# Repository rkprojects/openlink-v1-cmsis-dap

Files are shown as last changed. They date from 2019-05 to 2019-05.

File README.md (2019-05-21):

# OpenLink-V1 CMSIS-DAP Debug Unit

Project home page: [https://ravikiranb.com/projects/cmsis-dap-debug/](https://ravikiranb.com/projects/cmsis-dap-debug/)

Build your own simple low cost CMSIS-DAP Debug Unit with USB HID interface 
to debug any ARM Cortex based microcontroller.

## Get Hardware and Firmware Files

$ git clone https://github.com/rkprojects/openlink-v1-cmsis-dap.git

# Hardware

* 55x30 mm board size.
* Low cost, Low pin count MCU STM32F070F6P6.
* Micro USB type B connector.
* 10-pin cortex debug connector
* All GPIOs on Headers.

## Design Files and Gerber

Schematic and PCB Layout files are in folder *openlink-v1-cmsis-dap/hardware/*  
Gerber files are in folder *openlink-v1-cmsis-dap/hardware/gerber/*  
BOM file is in folder *openlink-v1-cmsis-dap/hardware/docs/*  

Schematic and PCB Layout designed with [DipTrace Version 3.3.1.3 (Freeware)](https://diptrace.com/)  

## Notes on DRC

Before sending gerber files to fabrication please cross check the design rules 
with your PCB manufacturer's specifications and rerun DRC.

Current DRC violations waved off:  

* J3.1 and J3.5 Drill to SMD pad clearance is set to 12 mil as per my PCB manufacturer's specifications however 
in manufacturer's review it was waved off.  
* Y1.1 and Y1.2: Footprint design of Y1 (crystal) is a hybrid one (through hole pad overlapping SMD pad) 
with possibility of mounting either SMD or through hole crystal. Preferred part is SMD, however 
if you wish to use through hole part then while soldering raise the height of crystal such that 
metal case does not touch SMD pads.

# Firmware

## Software Requirements

* GCC ARM Toolchain
* [Keil MDK for ARM](http://www.keil.com/products/arm/mdk.asp) if you wish to validate the debug unit. 
Lite edition is sufficient for this project. 
You could also use [MDK for STM32F0](https://www2.keil.com/stmicroelectronics-stm32/mdk)
* [STM32CubeProgrammer](https://www.st.com/en/development-tools/stm32cubeprog.html) to flash firmware in USB DFU mode.
* Tested on OS: Windows 10 Build 14393.

## Source Code

Firmware source codes are in folder *openlink-v1-cmsis-dap/firmware/*

Pre-built binaries are present in the *openlink-v1-cmsis-dap/firmware/build/* directory. 
If you wish to rebuild then you may have to modify the Makefile to correctly point 
to toolchain binaries and run make.

## Flash Firmware

* Close J5.1-2 pins with jumper cap to boot from System memory in USB DFU mode.
* Connect the debug unit with USB cable to PC host.
* Start STM32CubeProgrammer and select USB as bootloader interface option. 
	* Click **Refresh** icon - Device information fields will get updated.
	* Click **Connect**.
	* Click on **Open file** tab and select *openlink_v1_cmsis_dap.hex* file 
	in *openlink-v1-cmsis-dap/firmware/build/* directory.
	* Click **Download** to flash.
	* Post download click **Disconnect**.
* Open J5.1-2 pins and close J5.2-3 pins with jumper cap to boot from Flash memory.
* Reset the board with **Reset** switch. There is no need to power cycle the board.
* Board should now get detected as USB HID device, cross check this in Device manager.

## Validate Debug Unit

* CMSIS DAP Firmware Validation project is in 
folder *openlink-v1-cmsis-dap/firmware/Validation/MDK5*.
* Follow the instructions in the readme.txt file there.
* In the step where CMSIS-DAP debugger needs to be selected, select **OpenLink-V1 CMSIS-DAP**.
* For specific example with LPC4357 MCU based target 
board refer to [project home page](https://ravikiranb.com/projects/cmsis-dap-debug/).

# Pending Stuff

* JTAG interface of the debug unit is not yet tested as 
all the Cortex-M boards I have are designed with SWD debug port. 
However JTAG interface is completely implemented in firmware.
* Current 10-pin debug connector (J4) is of through hole type with 1.27mm pitch. Commonly
used connectors are of SMD type compatible with samtec FTSH-105- styles.

# License

Copyright 2019 Ravikiran Bukkasagara <contact@ravikiranb.com>

This project uses multiple licenses:

*   
**Schematic and PCB Layout** design files are licensed under a 
[Creative Commons Attribution-ShareAlike 4.0 International License](http://creativecommons.org/licenses/by-sa/4.0/)
* **CMSIS DAP firmware code** is licensed under [Apache License, Version 2.0](http://www.apache.org/licenses/LICENSE-2.0)
* **STMicroelectronics supplied USB Middleware, HAL, LL drivers and startup source codes** are licensed 
under [Ultimate Liberty license SLA0044](http://www.st.com/SLA0044)
* **Code to bridge USB and DAP data flow** is licensed under [Apache License, Version 2.0](http://www.apache.org/licenses/LICENSE-2.0)
* Each source/header file specifies corresponding license/copyright notices.

All firmware source codes and hardware design files in this project are distributed on an "AS IS" BASIS,
WITHOUT WARRANTIES OR CONDITIONS OF ANY KIND, either express or implied.
See the License for the specific language governing permissions and
limitations under the License.

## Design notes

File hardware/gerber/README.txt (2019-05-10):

Filename meaning:

1) cmsis_dap.drl: NC Drill file, contains both plated and non-plated holes.
2) cmsis_dap.gbl: Gerber bottom copper layer.
3) cmsis_dap.gbo: Gerber bottom silk screen layer.
4) cmsis_dap.gbs: Gerber bottom solder mask layer.
5) cmsis_dap.gko: Gerber Board outline.
6) cmsis_dap.gtl: Gerber top copper layer.
7) cmsis_dap.gto: Gerber top silk screen layer.
8) cmsis_dap.gts: Gerber top solder mask layer.

Board Specifications:
Board Size: X = 55mm, Y = 30mm.

Board delivery form: Cut to single unit (No panel).

Layers: 2 (double sided)

Board Thickness: 1.6mm

Start copper thickness: 17.50 micron

Finished outer copper thickness: 35 micron

Surfach Finish: HAL

Solder mask color: Preferred Green. 
But for prototyping, manufacturer's choice if on shared project.

Silk screen text color: Preferred White. 
But for prototyping, manufacturer's choice if on shared project.

Impedance control: Not required.

Blind & Buried Via: Not present.

-END-

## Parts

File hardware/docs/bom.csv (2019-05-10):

# | RefDes | Value | Name | Pattern | Quantity | Description | Part Weblink | Alternate Part
1 | C1, C2, C3 | 0.1u | CAP_0805 | CAP_0805 | 3 | >= 6V, 10%
2 | C4, C5 | 10u | Capacitor_Pol_SMD1206 | CAP_1206 | 2 | Tantalum >= 6V, 10%
3 | C6, C7 | 20p | CAP_0805 | CAP_0805 | 2 | >= 6V, 10%
4 | D1 | POWER | DIO_LED_1 | DIO_0805 | 1 | SMD LED
5 | D2 | RUN | DIO_LED_1 | DIO_0805 | 1 | SMD LED
6 | D3 | CONNECT | DIO_LED_1 | DIO_0805 | 1 | SMD LED
7 | D4 | TARGET | DIO_LED_1 | DIO_0805 | 1 | SMD LED
8 | J1, J2 |  | HDR-1x8 | HDR-1x8 | 2 | 2.54mm pitch Header
9 | J3 |  | MicroUSB | MicroUSB_B | 1 | Sunrom Model 4358 | https://www.sunrom.com/m/4358
10 | J4 |  | Cortex JTAG SWD Debug | HDR-2x5S/1.27x1.27/6x6 | 1 | 1.27mm pitch IDC
11 | J5 |  | HDR-1x3 | HDR-1x3 | 1 | 2.54mm pitch Header
12 | R1, R2, R3 | 0 | RES_0805 | RES_0805_MARKED | 3 | <= 5%, 125mW
13 | R4, R5, R6, R7 | 330 | RES_0805 | RES_0805_MARKED | 4 | <= 5%, 125mW
14 | SB1 |  | Solder_Bridge_3P | Solder_Bridge_SMD_3P | 1 | Solder Bridge
15 | SW1 |  | Tactile Switch 4388 | 3x6x2.5mm | 1 | Sunrom Model 4388 | https://www.sunrom.com/m/4388
16 | U1 | AMS1117-3.3 | REG1117-3.3 | SOT223-4 | 1 | AMS1117-3.3
17 | U2 |  | STM32F070F6Px | TSSOP-20 | 1 | STM32F070F6P6
18 | Y1 | 8MHz | HC49/4H_SMX | HC-49 | 1 | FOXSDLF/080-20

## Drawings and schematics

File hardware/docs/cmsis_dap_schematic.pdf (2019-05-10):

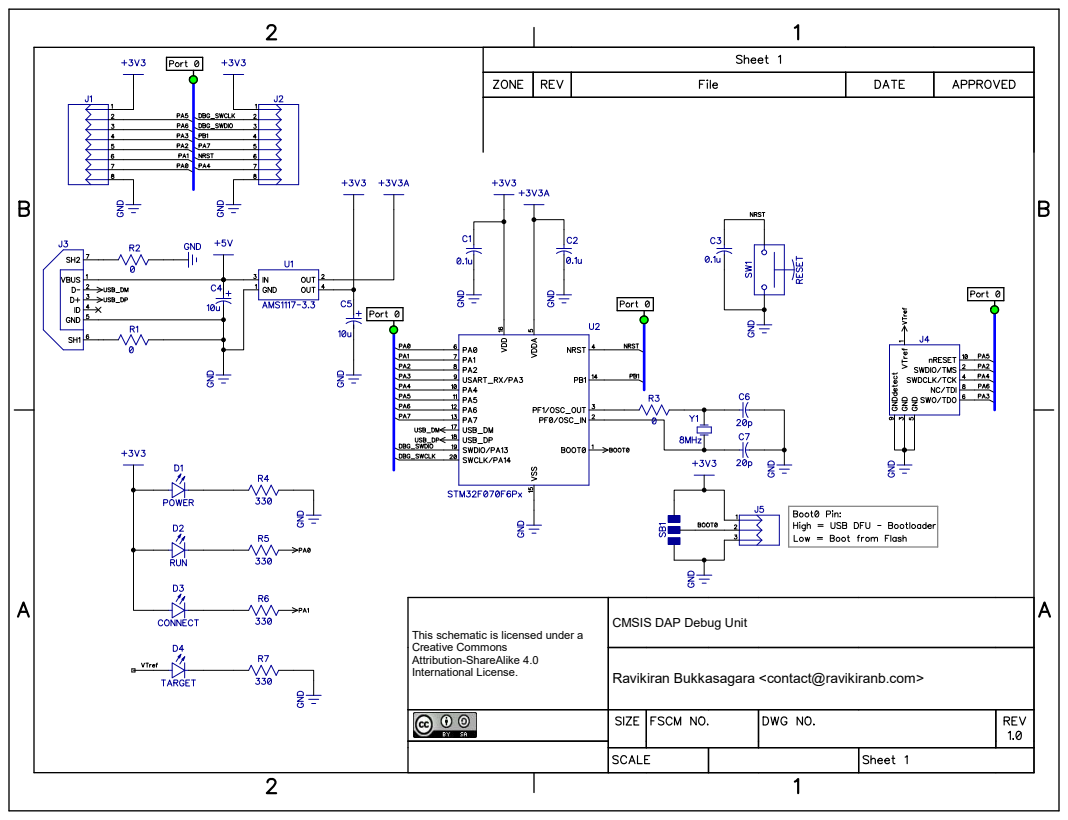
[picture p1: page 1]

CMSIS DAP Debug Unit

This schematic is licensed under a
Creative Commons
Attribution-ShareAlike 4.0
International License.

Ravikiran Bukkasagara <contact@ravikiranb.com>

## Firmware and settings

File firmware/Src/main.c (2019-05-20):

/*

Copyright 2019 Ravikiran Bukkasagara <contact@ravikiranb.com>

Licensed under the Apache License, Version 2.0 (the "License");
you may not use this file except in compliance with the License.
You may obtain a copy of the License at

    http://www.apache.org/licenses/LICENSE-2.0

Unless required by applicable law or agreed to in writing, software
distributed under the License is distributed on an "AS IS" BASIS,
WITHOUT WARRANTIES OR CONDITIONS OF ANY KIND, either express or implied.
See the License for the specific language governing permissions and
limitations under the License.

*/

#include "main.h"
#include "usb_device.h"
#include "DAP.h"
#include "DAP_config.h"
#include "cmsis_compiler.h"
#include "usbd_custom_hid_if.h"



extern USBD_HandleTypeDef hUsbDeviceFS;
uint8_t  USB_DAP_Requests [DAP_PACKET_COUNT][DAP_PACKET_SIZE];  
uint8_t  USB_DAP_Responses[DAP_PACKET_COUNT][DAP_PACKET_SIZE];

static uint32_t CommonIndex;  //Current "Request - Response" being processed index linked together.
static uint32_t ResponseIndexSend;
static uint32_t ResponsePendingCount;

volatile uint32_t RequestPendingCount;
extern volatile uint32_t RequestPauseProcessing;

void SystemClock_Config(void);
static void MX_GPIO_Init(void);
static void Send_USB_DAP_Response(void);
static void Timer_Init(void);


int main(void)
{
  uint32_t skip_sending_response;
	
	HAL_Init();

  // Set System clock to 48MHz. 
	SystemClock_Config();

  CommonIndex = 0;
	ResponseIndexSend = 0;
	ResponsePendingCount = 0;
	RequestPendingCount = 0;
	
	MX_GPIO_Init();
	
	MX_USB_DEVICE_Init();
	
	// For DAP time stamp.
	Timer_Init();
	
  DAP_Setup();
  
	while (1) 
	{
		/* 
			Cortex-M0 does not support synchronizing instructions.
			RequestPendingCount variable has a potential racing condition.
			Disabling interrupts while update is a choice.
			Systick interrupt will cause wakeup in case of out of sync between
			USB interrupt and WFI call here.
		*/
		
		if (RequestPendingCount == 0) {
			__WFI();
		}
		
		while ((RequestPendingCount > 0) && (ResponsePendingCount < DAP_PACKET_COUNT)) {
			
			if (USB_DAP_Requests[CommonIndex][0] == ID_DAP_QueueCommands) {
				// Pause request processing until all queue commands are received.
				if (RequestPauseProcessing)
					break;
				
				USB_DAP_Requests[CommonIndex][0] = ID_DAP_ExecuteCommands;
				
				// Avoid sending usb response during processing queued commands.
				skip_sending_response = 1;
			}
			else {
				skip_sending_response = 0;
			}
			
			DAP_ExecuteCommand(USB_DAP_Requests[CommonIndex], USB_DAP_Responses[CommonIndex]);
			
			RequestPendingCount--;
			ResponsePendingCount++;
			CommonIndex++;
			if (CommonIndex >= DAP_PACKET_COUNT) {
				CommonIndex = 0;
			}
			
			if (skip_sending_response == 0)
				Send_USB_DAP_Response();
		}
		
		if (ResponsePendingCount > 0) {
			Send_USB_DAP_Response();
		}
	}
}

static void Send_USB_DAP_Response(void) {
	
	USBD_CUSTOM_HID_HandleTypeDef *hhid = (USBD_CUSTOM_HID_HandleTypeDef*) hUsbDeviceFS.pClassData;
			
	if (hhid->state == CUSTOM_HID_IDLE) {
		USBD_CUSTOM_HID_SendReport(&hUsbDeviceFS, USB_DAP_Responses[ResponseIndexSend], DAP_PACKET_SIZE);
		ResponseIndexSend++;
		if (ResponseIndexSend >= DAP_PACKET_COUNT) {
			ResponseIndexSend = 0;
		}
		ResponsePendingCount--;
	}
}

static void Timer_Init(void) {
	/* Chain TIM1 (prescaler) -> TIM3 (counter) to create 
		free-running 32bit timer {TIM3, TIM1} with 1us tick.
	*/
	
	// Timer HAL APIs are not used anywhere else.
	TIM_HandleTypeDef    TimerHandle;
	TIM_SlaveConfigTypeDef TIM3_SlaveConfig;
	TIM_MasterConfigTypeDef TIM1_MasterConfig;
	
	// Configure TIM3 as slave.
	memset(&TimerHandle, 0, sizeof(TimerHandle));
	
	TimerHandle.Instance = TIM3;
	TimerHandle.Init.Period            = 0xffff;
  TimerHandle.Init.Prescaler         = 0;
  TimerHandle.Init.ClockDivision     = 0;
  TimerHandle.Init.CounterMode       = TIM_COUNTERMODE_UP;
  TimerHandle.Init.RepetitionCounter = 0;
  TimerHandle.Init.AutoReloadPreload = TIM_AUTORELOAD_PRELOAD_DISABLE;

  if (HAL_TIM_Base_Init(&TimerHandle) != HAL_OK) {
    Error_Handler();
  }
	
	TIM3_SlaveConfig.SlaveMode = TIM_SLAVEMODE_EXTERNAL1;
	TIM3_SlaveConfig.InputTrigger = TIM_TS_ITR0;
	TIM3_SlaveConfig.TriggerPolarity = TIM_TRIGGERPOLARITY_RISING; // don't care value
	TIM3_SlaveConfig.TriggerPrescaler = TIM_TRIGGERPRESCALER_DIV1; // don't care value
	TIM3_SlaveConfig.TriggerFilter = 0; // don't care value
	
	if (HAL_TIM_SlaveConfigSynchronization(&TimerHandle, &TIM3_SlaveConfig) != HAL_OK) {
		Error_Handler();
	}

  if (HAL_TIM_Base_Start(&TimerHandle) != HAL_OK) {
    Error_Handler();
  }
	
	// configure TIM1 as master.
	memset(&TimerHandle, 0, sizeof(TimerHandle));
	
	TimerHandle.Instance = TIM1;
	TimerHandle.Init.Period            = 0xffff;
  TimerHandle.Init.Prescaler         = (HAL_RCC_GetHCLKFreq() / TIMESTAMP_CLOCK) - 1;
  TimerHandle.Init.ClockDivision     = 0;
  TimerHandle.Init.CounterMode       = TIM_COUNTERMODE_UP;
  TimerHandle.Init.RepetitionCounter = 0;
  TimerHandle.Init.AutoReloadPreload = TIM_AUTORELOAD_PRELOAD_DISABLE;

  if (HAL_TIM_Base_Init(&TimerHandle) != HAL_OK) {
    Error_Handler();
  }
	
	TIM1_MasterConfig.MasterOutputTrigger = TIM_TRGO_UPDATE;
	TIM1_MasterConfig.MasterSlaveMode = TIM_MASTERSLAVEMODE_ENABLE;
	
	if (HAL_TIMEx_MasterConfigSynchronization(&TimerHandle,  &TIM1_MasterConfig) != HAL_OK) {
		Error_Handler();
	}

	if (HAL_TIM_Base_Start(&TimerHandle) != HAL_OK) {
    Error_Handler();
  }
}

void SystemClock_Config(void)
{
  RCC_OscInitTypeDef RCC_OscInit = {0};
  RCC_ClkInitTypeDef RCC_ClkInit = {0};
  RCC_PeriphCLKInitTypeDef PeriphClkInit = {0};

  /** Initializes the CPU, AHB and APB busses clocks 
  */
  RCC_OscInit.OscillatorType = RCC_OSCILLATORTYPE_HSE;
  RCC_OscInit.HSEState = RCC_HSE_ON;
  RCC_OscInit.PLL.PLLState = RCC_PLL_ON;
  RCC_OscInit.PLL.PLLSource = RCC_PLLSOURCE_HSE;
  RCC_OscInit.PLL.PLLMUL = RCC_PLL_MUL6;
  RCC_OscInit.PLL.PREDIV = RCC_PREDIV_DIV1;
  if (HAL_RCC_OscConfig(&RCC_OscInit) != HAL_OK)
  {
    Error_Handler();
  }
  /** Initializes the CPU, AHB and APB busses clocks 
  */
  RCC_ClkInit.ClockType = RCC_CLOCKTYPE_HCLK|RCC_CLOCKTYPE_SYSCLK
                              |RCC_CLOCKTYPE_PCLK1;
  RCC_ClkInit.SYSCLKSource = RCC_SYSCLKSOURCE_PLLCLK;
  RCC_ClkInit.AHBCLKDivider = RCC_SYSCLK_DIV1;
  RCC_ClkInit.APB1CLKDivider = RCC_HCLK_DIV1;

  if (HAL_RCC_ClockConfig(&RCC_ClkInit, FLASH_LATENCY_1) != HAL_OK)
  {
    Error_Handler();
  }
  PeriphClkInit.PeriphClockSelection = RCC_PERIPHCLK_USB;
  PeriphClkInit.UsbClockSelection = RCC_USBCLKSOURCE_PLL;

  if (HAL_RCCEx_PeriphCLKConfig(&PeriphClkInit) != HAL_OK)
  {
    Error_Handler();
  }
  /** Enables the Clock Security System 
  */
  HAL_RCC_EnableCSS();
}


static void MX_GPIO_Init(void)
{
  GPIO_InitTypeDef GPIO_Init = {0};

  /* GPIO Ports Clock Enable */
  __HAL_RCC_GPIOF_CLK_ENABLE();
  __HAL_RCC_GPIOA_CLK_ENABLE();
  __HAL_RCC_GPIOB_CLK_ENABLE();

  /*Configure GPIO pins : PA0 PA1 PA4 PA5 
                           PA6 PA7 */
  GPIO_Init.Pin = GPIO_PIN_0|GPIO_PIN_1|GPIO_PIN_4|GPIO_PIN_5 
                          |GPIO_PIN_6|GPIO_PIN_7;
  GPIO_Init.Mode = GPIO_MODE_INPUT;
  GPIO_Init.Pull = GPIO_NOPULL;
  HAL_GPIO_Init(GPIOA, &GPIO_Init);

  /*Configure GPIO pin : PB1 */
  GPIO_Init.Pin = GPIO_PIN_1;
  GPIO_Init.Mode = GPIO_MODE_INPUT;
  GPIO_Init.Pull = GPIO_NOPULL;
  HAL_GPIO_Init(GPIOB, &GPIO_Init);
}

void Error_Handler(void)
{
  while(1);
}

#ifdef  USE_FULL_ASSERT
/**
  * @brief  Reports the name of the source file and the source line number
  *         where the assert_param error has occurred.
  * @param  file: pointer to the source file name
  * @param  line: assert_param error line source number
  * @retval None
  */
void assert_failed(char *file, uint32_t line)
{ 
	while(1);
}
#endif /* USE_FULL_ASSERT */

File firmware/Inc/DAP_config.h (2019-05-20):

/*
 * Copyright 2019 Ravikiran Bukkasagara <contact@ravikiranb.com>
 * 
 * Copyright (c) 2013-2017 ARM Limited. All rights reserved.
 *
 * SPDX-License-Identifier: Apache-2.0
 *
 * Licensed under the Apache License, Version 2.0 (the License); you may
 * not use this file except in compliance with the License.
 * You may obtain a copy of the License at
 *
 * www.apache.org/licenses/LICENSE-2.0
 *
 * Unless required by applicable law or agreed to in writing, software
 * distributed under the License is distributed on an AS IS BASIS, WITHOUT
 * WARRANTIES OR CONDITIONS OF ANY KIND, either express or implied.
 * See the License for the specific language governing permissions and
 * limitations under the License.
 *
 * ----------------------------------------------------------------------
 *
 * $Date:        1. December 2017
 * $Revision:    V2.0.0
 *
 * Project:      CMSIS-DAP Configuration
 * Title:        DAP_config.h CMSIS-DAP Configuration File (Template)
 *
 *---------------------------------------------------------------------------
 
	Modifications:
	1) Implementation of all DAP platform specific functions and macros.
	
 */

#ifndef __DAP_CONFIG_H__
#define __DAP_CONFIG_H__

#include <string.h>
#include <stdio.h>

#include "stm32f0xx_hal.h"


#define DAP_VENDOR_ID     "RavikiranB.com"
#define DAP_PRODUCT_ID    "OpenLink-V1 CMSIS-DAP"


// All JTAG/SWD pins are on Port A.
#define GPIO_PIN_nRESET     		GPIO_PIN_5
#define GPIO_PIN_nRESET_BIT 		5

#define GPIO_PIN_SWDIO_TMS  		GPIO_PIN_2
#define GPIO_PIN_SWDIO_TMS_BIT 	2

#define GPIO_PIN_SWDCLK_TCK 		GPIO_PIN_4
#define GPIO_PIN_SWDCLK_TCK_BIT 4

#define GPIO_PIN_TDI        GPIO_PIN_6
#define GPIO_PIN_TDI_BIT    6

#define GPIO_PIN_TDO        GPIO_PIN_3
#define GPIO_PIN_TDO_BIT    3

#define GPIO_PIN_LED_RUN      GPIO_PIN_0
#define GPIO_PIN_LED_RUN_BIT  0

#define GPIO_PIN_LED_CONNECT  		GPIO_PIN_1
#define GPIO_PIN_LED_CONNECT_BIT  1

//**************************************************************************************************
/** 
\defgroup DAP_Config_Debug_gr CMSIS-DAP Debug Unit Information
\ingroup DAP_ConfigIO_gr 
@{
Provides definitions about the hardware and configuration of the Debug Unit.

This information includes:
 - Definition of Cortex-M processor parameters used in CMSIS-DAP Debug Unit.
 - Debug Unit Identification strings (Vendor, Product, Serial Number).
 - Debug Unit communication packet size.
 - Debug Access Port supported modes and settings (JTAG/SWD and SWO).
 - Optional information about a connected Target Device (for Evaluation Boards).
*/

// TODO - Debug Unit Cortex-M Processor Header File
#include "cmsis_compiler.h"

/// Processor Clock of the Cortex-M MCU used in the Debug Unit.
/// This value is used to calculate the SWD/JTAG clock speed.
#define CPU_CLOCK               48000000U      ///< Specifies the CPU Clock in Hz.

/// Number of processor cycles for I/O Port write operations.
/// This value is used to calculate the SWD/JTAG clock speed that is generated with I/O
/// Port write operations in the Debug Unit by a Cortex-M MCU. Most Cortex-M processors
/// require 2 processor cycles for a I/O Port Write operation.  If the Debug Unit uses
/// a Cortex-M0+ processor with high-speed peripheral I/O only 1 processor cycle might be 
/// required.
#define IO_PORT_WRITE_CYCLES    2U              ///< I/O Cycles: 2=default, 1=Cortex-M0+ fast I/0.

/// Indicate that Serial Wire Debug (SWD) communication mode is available at the Debug Access Port.
/// This information is returned by the command \ref DAP_Info as part of <b>Capabilities</b>.
#define DAP_SWD                 1               ///< SWD Mode:  1 = available, 0 = not available.

/// Indicate that JTAG communication mode is available at the Debug Port.
/// This information is returned by the command \ref DAP_Info as part of <b>Capabilities</b>.
#define DAP_JTAG                1               ///< JTAG Mode: 1 = available, 0 = not available.

/// Configure maximum number of JTAG devices on the scan chain connected to the Debug Access Port.
/// This setting impacts the RAM requirements of the Debug Unit. Valid range is 1 .. 255.
#define DAP_JTAG_DEV_CNT        4U              ///< Maximum number of JTAG devices on scan chain.

/// Default communication mode on the Debug Access Port.
/// Used for the command \ref DAP_Connect when Port Default mode is selected.
#define DAP_DEFAULT_PORT        1U              ///< Default JTAG/SWJ Port Mode: 1 = SWD, 2 = JTAG.

/// Default communication speed on the Debug Access Port for SWD and JTAG mode.
/// Used to initialize the default SWD/JTAG clock frequency.
/// The command \ref DAP_SWJ_Clock can be used to overwrite this default setting.
#define DAP_DEFAULT_SWJ_CLOCK   1000000U        ///< Default SWD/JTAG clock frequency in Hz.
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

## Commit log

2019-05-10 Added design and code files.
    [bom.csv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]
2019-05-14 Added firmware version in usb device descriptor.
    bcdDevice field in USB Device descriptor now reflects
    device firmware version which is different from DAP firmware
    version number.
2019-05-15 Added DAP SWO UART Trace
    Implemented CMSIS USART Driver interface for ST HAL UART for SWO
    tracing in UART mode. SWO buffer size set to = 1KB.
    Unused heap memory recovered for SWO buffer. More memory
    optimization is possible.
    SWO trace capture tested with Keil uVision:
    SWO Debug (printf) viewer from ITM port 0 works fine.
    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
2019-05-15 SWO trace now implemented.
2019-05-16 Implemented Test domain timer
    Timestamp enabled with TIM3,TIM1
2019-05-21 Assigned unique USB VID:PID 1209:2010 to device
    http://pid.codes/1209/2010/
